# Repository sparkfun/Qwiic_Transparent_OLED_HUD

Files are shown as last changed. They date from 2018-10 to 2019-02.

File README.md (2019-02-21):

SparkFun Qwiic Transparent OLED HUD
========================================

Qwiic WiseChip Transparent OLED HUD (https://www.sparkfun.com/products/14691)

[*SparkFun Qwiic Transparent OLED HUD Hookup Guide (LCD-15079)*](https://www.sparkfun.com/products/14691)

Qwiic Breakout for the WiseChip US-0011GMIAG01 OLED HUD. Clear screens are no longer a thing of the Sci-Fi world! The Qwiic Transparent OLED HUD is SparkFun's answer to all of your futuristic transparent HUD needs. Designed for use in vehicle heads-up displays, this OLED panel is brilliant in the dark but easily visible in daylight. The display is "area colored" meaning that while no one segment can change colors, there are different colored segments on the display.

Repository Contents
-------------------

* **/Hardware** - Eagle design files (.brd, .sch)
* **/Production** - Production panel files (.brd)

Documentation
--------------
* **[Library](https://github.com/sparkfun/SparkFun_WiseChip_HUD_Library)** - Arduino library
* **[Hookup Guide](https://learn.sparkfun.com/tutorials/qwiic-transparent-oled-hud-hookup-guide)** - Basic hookup guide

Product Versions
----------------

* **[LCD-15079](https://www.sparkfun.com/products/15079)** - SparkFun Red Version
* **[SPX-14691](https://www.sparkfun.com/products/14691)** - SparkX Version

License Information
-------------------

This product is _**open source**_! 

Please review the LICENSE.md file for license information. 

If you have any questions or concerns on licensing, please contact techsupport@sparkfun.com.

Distributed as-is; no warranty is given.

- Your friends at SparkFun.

_<COLLABORATION CREDIT>_

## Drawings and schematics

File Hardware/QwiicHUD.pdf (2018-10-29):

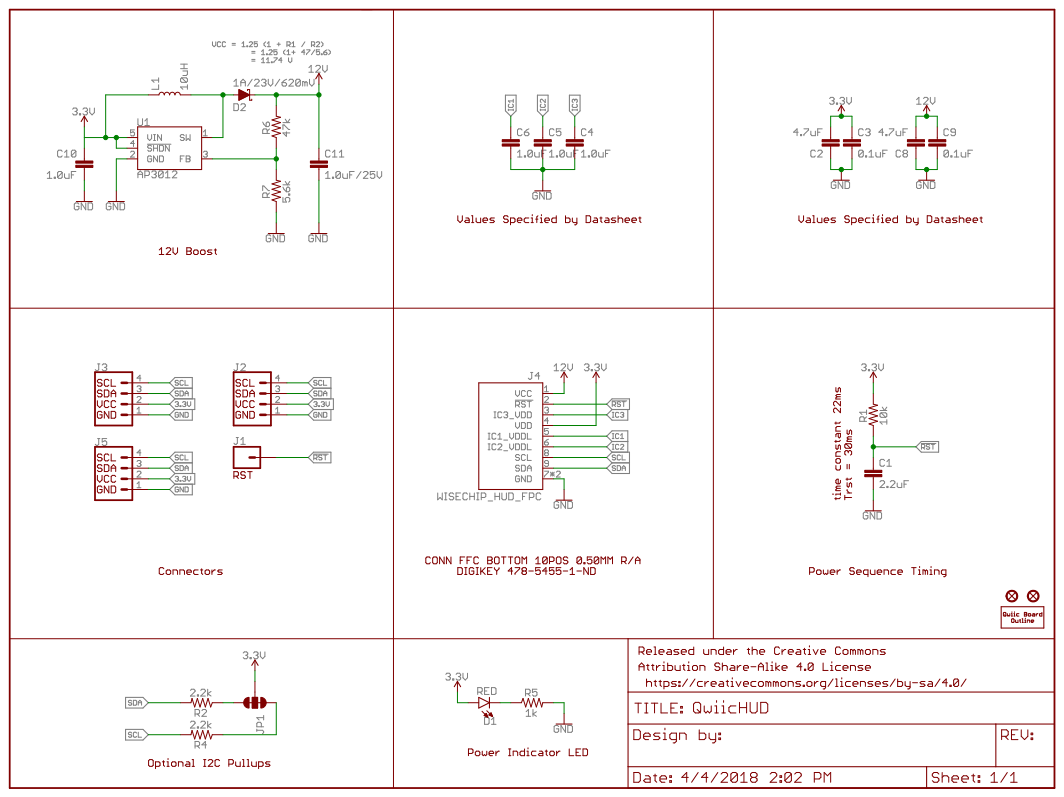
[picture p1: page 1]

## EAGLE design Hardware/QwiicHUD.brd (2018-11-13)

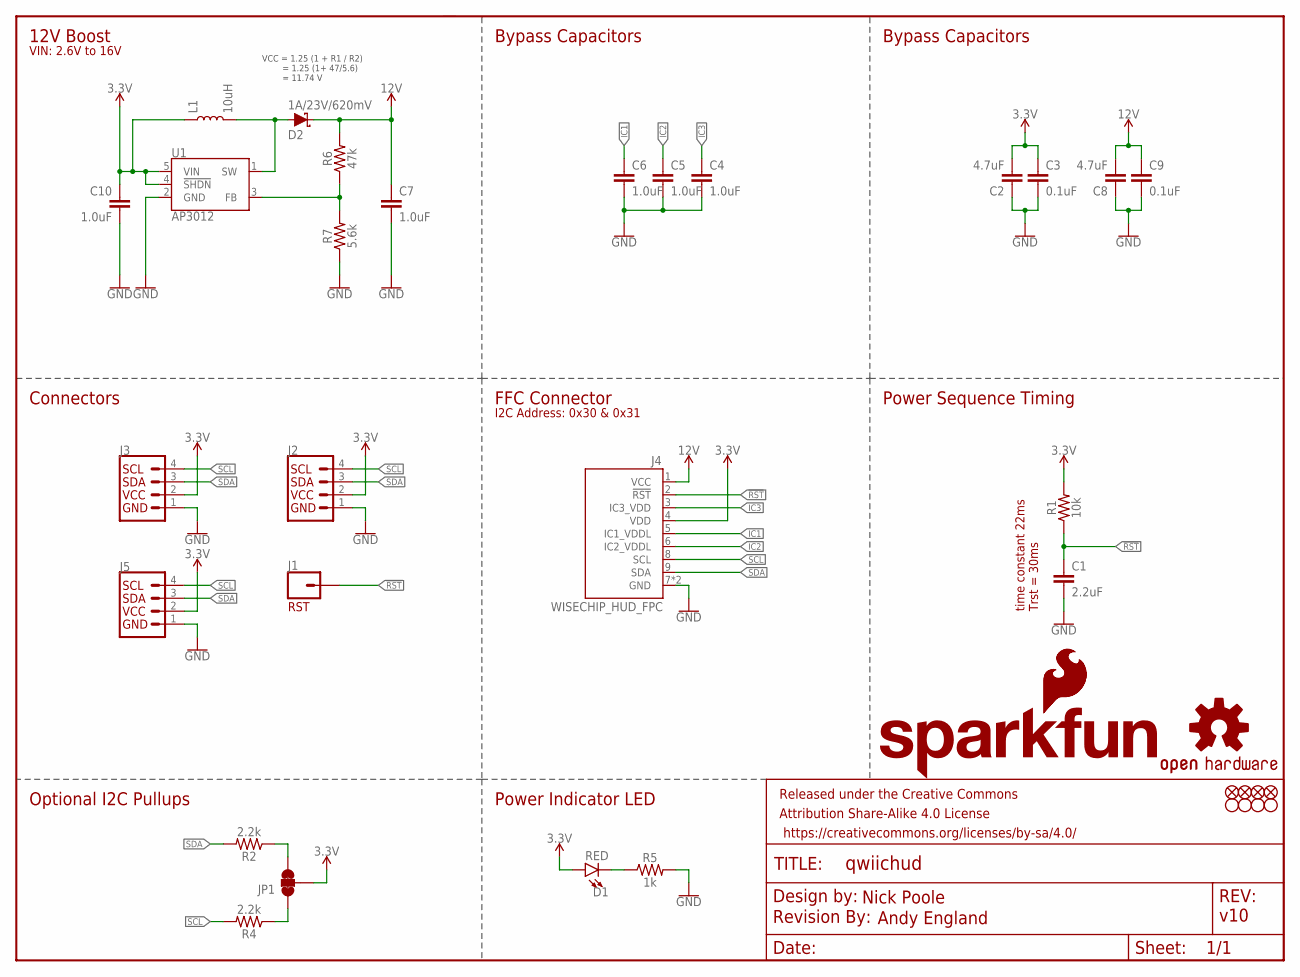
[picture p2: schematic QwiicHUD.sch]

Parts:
C1: 2.2uF; 0603
C2, C8: 4.7uF; 0603
C3, C9: 0.1uF; 0603
C4, C5, C6, C10: 1.0uF; 0603
C7: 1.0uF; 0805
D1: RED; LED-0603
D2: 1A/23V/620mV; SOD-323
FD1, FD2, FD3, FD4: FIDUCIALUFIDUCIAL; FIDUCIAL-MICRO
FRAME1: FRAME-LETTER; CREATIVE_COMMONS
H1, H2, H3, H4: STAND-OFF
J1: CONN_01PTH_NO_SILK_YES_STOP; 1X01_NO_SILK
J2: I2C_STANDARD_NO_SILK; 1X04_NO_SILK
J3, J5: QWIIC_CONNECTORJS-1MM; 1X04_1MM_RA
J4: WISECHIP_HUD_FPC; SERIES6288
JP1: JUMPER-SMT_3_2-NC_TRACE_SILK; SMT-JUMPER_3_2-NC_TRACE_SILK
L1: 10uH; INDUCTOR_4.7UH
LOGO1: OSHW-LOGOS; OSHW-LOGO-S
LOGO2: SFE_LOGO_NAME_FLAME.1_INCH; SFE_LOGO_NAME_FLAME_.1
LOGO3: SFE_LOGO_FLAME.1_INCH; SFE_LOGO_FLAME_.1
LOGO4: REVISION
R1: 10k; 0603
R2, R4: 2.2k; 0603
R5: 1k; 0603
R6: 47k; 0603
R7: 5.6k; 0603
U1: AP3012; SOT23-5

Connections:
3.3V: C2.2, C3.1, C10.1, D1.A, J2.2 (VCC), J3.2, J4.4 (VDD), J5.2, JP1.2, L1.P$1 (1), R1.2, U1.4 (!SHDN!), U1.5 (VIN)
12V: C7.1, C8.2, C9.1, D2.C, J4.1 (VCC), R6.2
!RST: C1.1, J1.1, J4.2 (!RST), R1.1
GND: C1.2, C2.1, C3.2, C4.2, C5.2, C6.2, C7.2, C8.1, C9.2, C10.2, J2.1 (GND), J3.1, J4.7 (GND), J4.10 (GND), J5.1, R5.2, R7.1, U1.2 (GND)
IC1: C6.1, J4.5 (IC1_VDDL)
IC2: C5.1, J4.6 (IC2_VDDL)
IC3: C4.1, J4.3 (IC3_VDD)
unnamed: JP1.3, R2.1
unnamed: JP1.1, R4.1
unnamed: D1.C, R5.1
unnamed: D2.A, L1.P$2 (2), U1.1 (SW)
unnamed: R6.1, R7.2, U1.3 (FB)
SCL: J2.4 (SCL), J3.4, J4.8 (SCL), J5.4, R4.2
SDA: J2.3 (SDA), J3.3, J4.9 (SDA), J5.3, R2.2

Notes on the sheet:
time constant 22ms Trst = 30ms
FFC Connector
Connectors
Power Sequence Timing
Optional I2C Pullups
RST
Power Indicator LED
VCC = 1.25 (1 + R1 / R2) = 1.25 (1+ 47/5.6) = 11.74 V
12V Boost
Nick Poole
Andy England
v10
VIN: 2.6V to 16V
I2C Address: 0x30 & 0x31
Bypass Capacitors

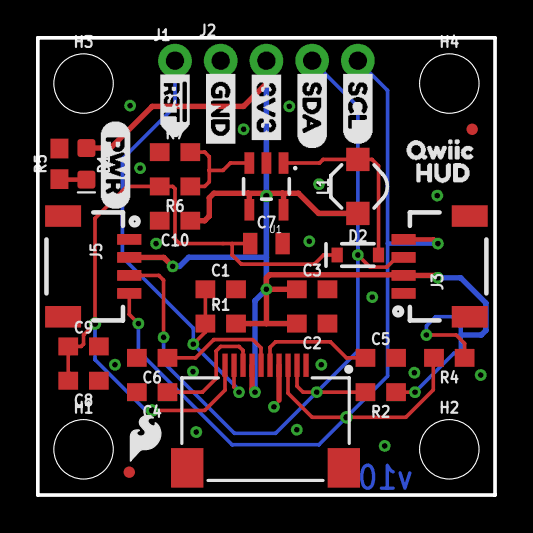
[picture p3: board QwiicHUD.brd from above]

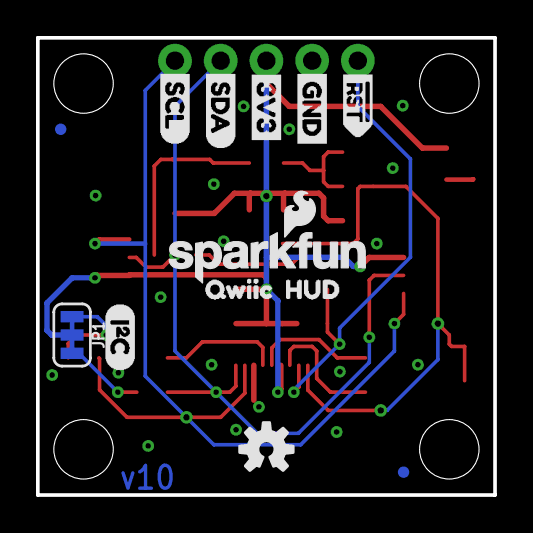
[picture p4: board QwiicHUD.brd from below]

Board: 2 copper layers, 25.4 x 25.4 mm, 55 parts (13 on the bottom side), 14 nets.

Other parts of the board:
U$1, U$14: #RST>
U$2, U$18: QWIIC0
U$3, U$19: HUD1
U$5, U$13: GND
U$6, U$12: 3V3
U$7, U$10: SDA
U$8, U$11: SCL
U$9: (PWR)
U$20: (I_SUPER2_C)

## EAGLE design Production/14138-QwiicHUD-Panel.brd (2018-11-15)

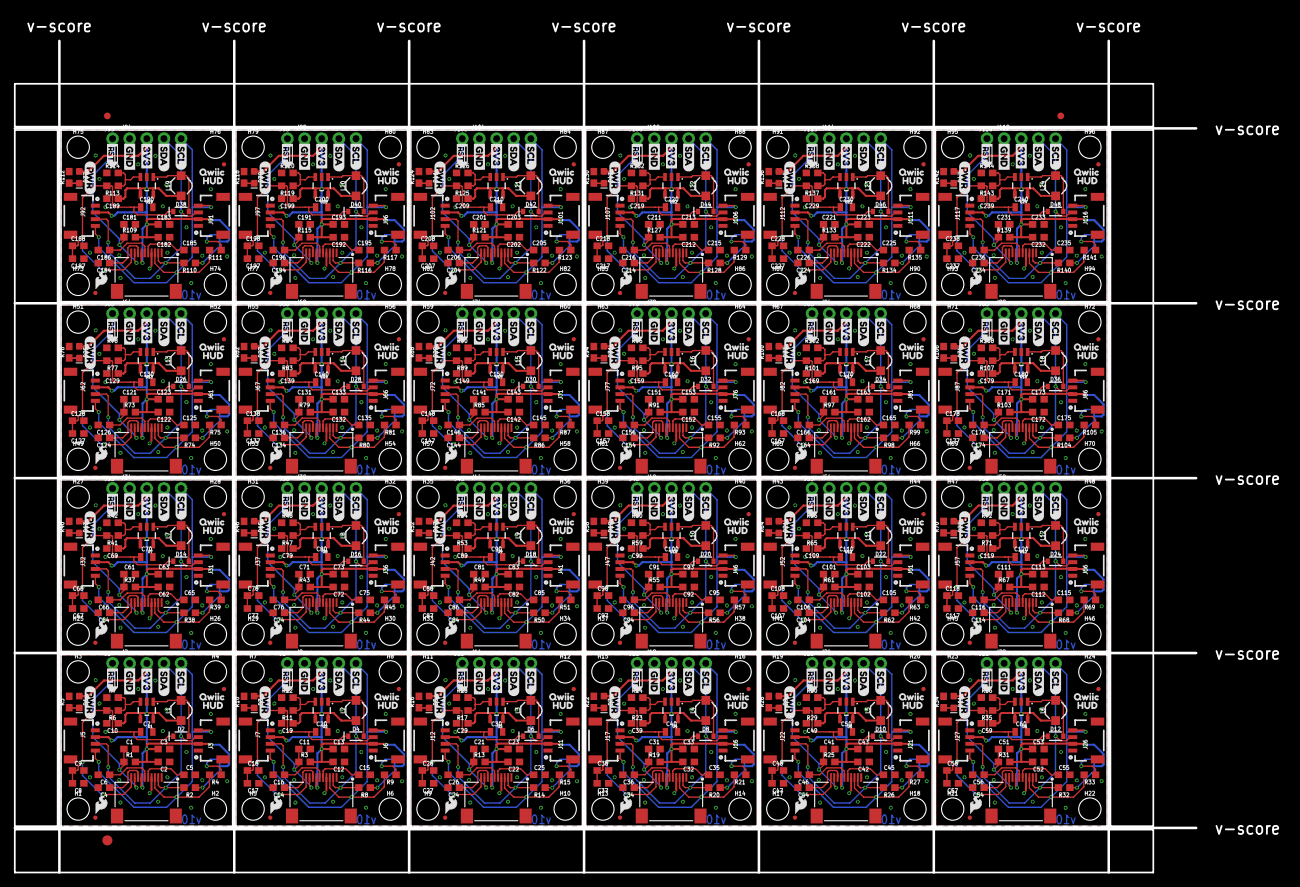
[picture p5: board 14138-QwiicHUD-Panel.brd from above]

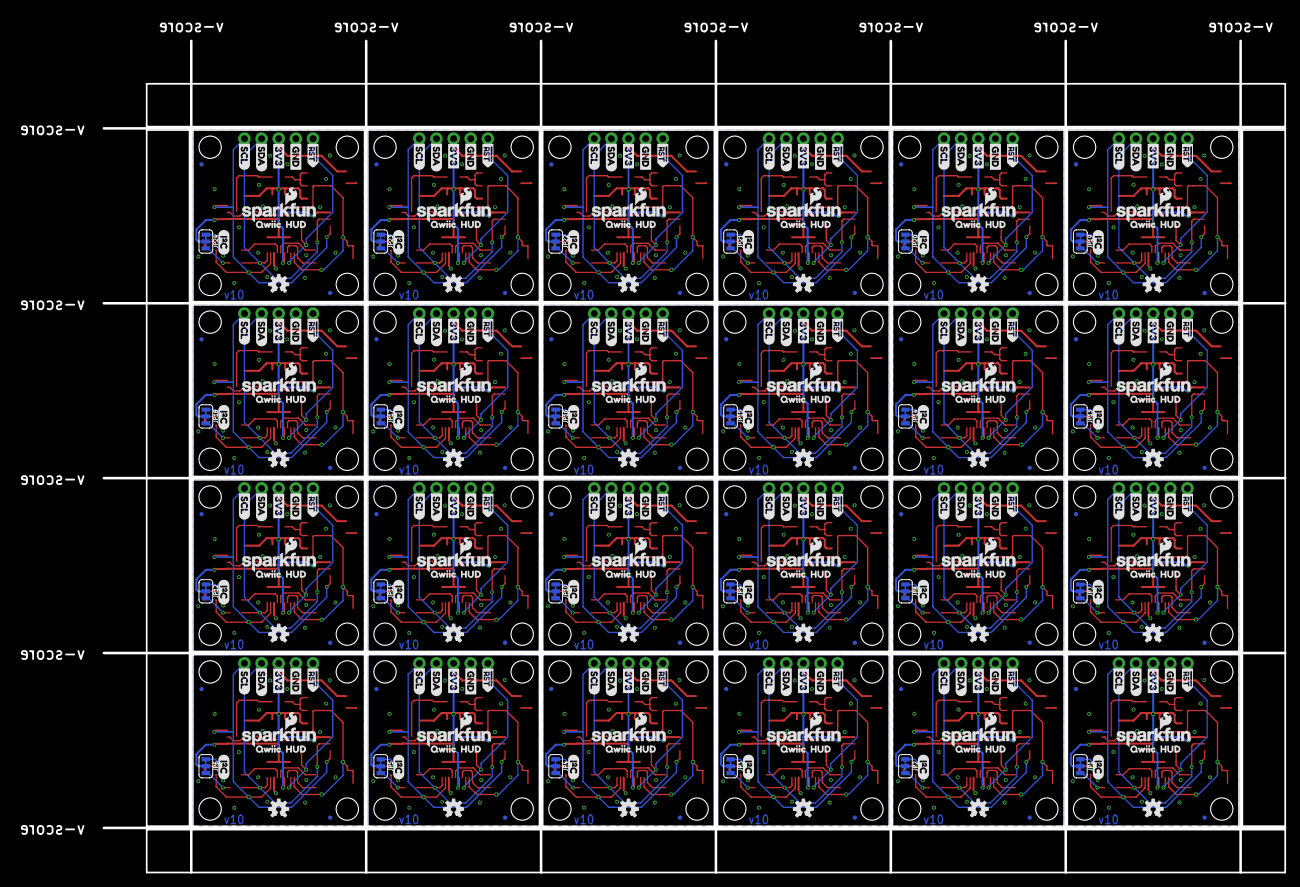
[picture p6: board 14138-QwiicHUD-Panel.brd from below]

Board: 2 copper layers, 175.0 x 123.2 mm, 1275 parts (312 on the bottom side), 336 nets.

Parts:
C1, C11, C21, C31, C41, C51, C61, C71, C81, C91, C101, C111, C121, C131, C141, C151, C161, C171, C181, C191, C201, C211, C221, C231: 2.2uF; 0603
C2, C8, C12, C17, C22, C27, C32, C37, C42, C47, C52, C57, C62, C67, C72, C77, C82, C87, C92, C97, C102, C107, C112, C117, C122, C127, C132, C137, C142, C147, C152, C157, C162, C167, C172, C177, C182, C187, C192, C197, C202, C207, C212, C217, C222, C227, C232, C237: 4.7uF; 0603
C3, C9, C13, C18, C23, C28, C33, C38, C43, C48, C53, C58, C63, C68, C73, C78, C83, C88, C93, C98, C103, C108, C113, C118, C123, C128, C133, C138, C143, C148, C153, C158, C163, C168, C173, C178, C183, C188, C193, C198, C203, C208, C213, C218, C223, C228, C233, C238: 0.1uF; 0603
C4, C5, C6, C10, C14, C15, C16, C19, C24, C25, C26, C29, C34, C35, C36, C39, C44, C45, C46, C49, C54, C55, C56, C59, C64, C65, C66, C69, C74, C75, C76, C79, C84, C85, C86, C89, C94, C95, C96, C99, C104, C105, C106, C109, C114, C115, C116, C119, C124, C125, C126, C129, C134, C135, C136, C139, C144, C145, C146, C149, C154, C155, C156, C159, C164, C165, C166, C169, C174, C175, C176, C179, C184, C185, C186, C189, C194, C195, C196, C199, C204, C205, C206, C209, C214, C215, C216, C219, C224, C225, C226, C229, C234, C235, C236, C239: 1.0uF; 0603
C7, C20, C30, C40, C50, C60, C70, C80, C90, C100, C110, C120, C130, C140, C150, C160, C170, C180, C190, C200, C210, C220, C230, C240: 1.0uF; 0805
D1, D3, D5, D7, D9, D11, D13, D15, D17, D19, D21, D23, D25, D27, D29, D31, D33, D35, D37, D39, D41, D43, D45, D47: RED; LED-0603
D2, D4, D6, D8, D10, D12, D14, D16, D18, D20, D22, D24, D26, D28, D30, D32, D34, D36, D38, D40, D42, D44, D46, D48: 1A/23V/620mV; SOD-323
E$1, E$2: FIDUCIAL-1X2
E$3: FIDUCIAL-1.5X3
FD1, FD2, FD3, FD4, FD5, FD6, FD7, FD8, FD9, FD10, FD11, FD12, FD13, FD14, FD15, FD16, FD17, FD18, FD19, FD20, FD21, FD22, FD23, FD24, FD25, FD26, FD27, FD28, FD29, FD30, FD31, FD32, FD33, FD34, FD35, FD36, FD37, FD38, FD39, FD40, FD41, FD42, FD43, FD44, FD45, FD46, FD47, FD48, FD49, FD50, FD51, FD52, FD53, FD54, FD55, FD56, FD57, FD58, FD59, FD60, FD61, FD62, FD63, FD64, FD65, FD66, FD67, FD68, FD69, FD70, FD71, FD72, FD73, FD74, FD75, FD76, FD77, FD78, FD79, FD80, FD81, FD82, FD83, FD84, FD85, FD86, FD87, FD88, FD89, FD90, FD91, FD92, FD93, FD94, FD95, FD96: FIDUCIALUFIDUCIAL; FIDUCIAL-MICRO
H1, H2, H3, H4, H5, H6, H7, H8, H9, H10, H11, H12, H13, H14, H15, H16, H17, H18, H19, H20, H21, H22, H23, H24, H25, H26, H27, H28, H29, H30, H31, H32, H33, H34, H35, H36, H37, H38, H39, H40, H41, H42, H43, H44, H45, H46, H47, H48, H49, H50, H51, H52, H53, H54, H55, H56, H57, H58, H59, H60, H61, H62, H63, H64, H65, H66, H67, H68, H69, H70, H71, H72, H73, H74, H75, H76, H77, H78, H79, H80, H81, H82, H83, H84, H85, H86, H87, H88, H89, H90, H91, H92, H93, H94, H95, H96: STAND-OFF
J1, J8, J13, J18, J23, J28, J33, J38, J43, J48, J53, J58, J63, J68, J73, J78, J83, J88, J93, J98, J103, J108, J113, J118: 1X01_NO_SILK
J2, J9, J14, J19, J24, J29, J34, J39, J44, J49, J54, J59, J64, J69, J74, J79, J84, J89, J94, J99, J104, J109, J114, J119: 1X04_NO_SILK
J3, J5, J6, J7, J11, J12, J16, J17, J21, J22, J26, J27, J31, J32, J36, J37, J41, J42, J46, J47, J51, J52, J56, J57, J61, J62, J66, J67, J71, J72, J76, J77, J81, J82, J86, J87, J91, J92, J96, J97, J101, J102, J106, J107, J111, J112, J116, J117: 1X04_1MM_RA
J4, J10, J15, J20, J25, J30, J35, J40, J45, J50, J55, J60, J65, J70, J75, J80, J85, J90, J95, J100, J105, J110, J115, J120: WISECHIP_HUD_FPC; SERIES6288
JP1, JP2, JP3, JP4, JP5, JP6, JP7, JP8, JP9, JP10, JP11, JP12, JP13, JP14, JP15, JP16, JP17, JP18, JP19, JP20, JP21, JP22, JP23, JP24: SMT-JUMPER_3_2-NC_TRACE_SILK
L1, L2, L3, L4, L5, L6, L7, L8, L9, L10, L11, L12, L13, L14, L15, L16, L17, L18, L19, L20, L21, L22, L23, L24: 10uH; INDUCTOR_4.7UH
LOGO1, LOGO6, LOGO9, LOGO12, LOGO15, LOGO18, LOGO21, LOGO24, LOGO27, LOGO30, LOGO33, LOGO36, LOGO39, LOGO42, LOGO45, LOGO48, LOGO51, LOGO54, LOGO57, LOGO60, LOGO63, LOGO66, LOGO69, LOGO72: OSHW-LOGOS; OSHW-LOGO-S
LOGO2, LOGO4, LOGO7, LOGO10, LOGO13, LOGO16, LOGO19, LOGO22, LOGO25, LOGO28, LOGO31, LOGO34, LOGO37, LOGO40, LOGO43, LOGO46, LOGO49, LOGO52, LOGO55, LOGO58, LOGO61, LOGO64, LOGO67, LOGO70: SFE_LOGO_NAME_FLAME.1_INCH; SFE_LOGO_NAME_FLAME_.1
LOGO3, LOGO5, LOGO8, LOGO11, LOGO14, LOGO17, LOGO20, LOGO23, LOGO26, LOGO29, LOGO32, LOGO35, LOGO38, LOGO41, LOGO44, LOGO47, LOGO50, LOGO53, LOGO56, LOGO59, LOGO62, LOGO65, LOGO68, LOGO71: SFE_LOGO_FLAME.1_INCH; SFE_LOGO_FLAME_.1
R1, R3, R13, R19, R25, R31, R37, R43, R49, R55, R61, R67, R73, R79, R85, R91, R97, R103, R109, R115, R121, R127, R133, R139: 10k; 0603
R2, R4, R8, R9, R14, R15, R20, R21, R26, R27, R32, R33, R38, R39, R44, R45, R50, R51, R56, R57, R62, R63, R68, R69, R74, R75, R80, R81, R86, R87, R92, R93, R98, R99, R104, R105, R110, R111, R116, R117, R122, R123, R128, R129, R134, R135, R140, R141: 2.2k; 0603
R5, R10, R16, R22, R28, R34, R40, R46, R52, R58, R64, R70, R76, R82, R88, R94, R100, R106, R112, R118, R124, R130, R136, R142: 1k; 0603
R6, R11, R17, R23, R29, R35, R41, R47, R53, R59, R65, R71, R77, R83, R89, R95, R101, R107, R113, R119, R125, R131, R137, R143: 47k; 0603
R7, R12, R18, R24, R30, R36, R42, R48, R54, R60, R66, R72, R78, R84, R90, R96, R102, R108, R114, R120, R126, R132, R138, R144: 5.6k; 0603
U1, U2, U3, U4, U5, U6, U7, U8, U9, U10, U11, U12, U13, U14, U15, U16, U17, U18, U19, U20, U21, U22, U23, U24: AP3012; SOT23-5
U$1, U$4, U$14, U$27, U$33, U$43, U$49, U$59, U$65, U$75, U$81, U$91, U$97, U$107, U$113, U$123, U$129, U$139, U$145, U$155, U$161, U$171, U$177, U$187, U$193, U$203, U$209, U$219, U$225, U$235, U$241, U$251, U$257, U$267, U$273, U$283, U$289, U$299, U$305, U$315, U$321, U$331, U$337, U$347, U$353, U$363, U$369, U$379: #RST>
U$2, U$18, U$28, U$31, U$44, U$47, U$60, U$63, U$76, U$79, U$92, U$95, U$108, U$111, U$124, U$127, U$140, U$143, U$156, U$159, U$172, U$175, U$188, U$191, U$204, U$207, U$220, U$223, U$236, U$239, U$252, U$255, U$268, U$271, U$284, U$287, U$300, U$303, U$316, U$319, U$332, U$335, U$348, U$351, U$364, U$367, U$380, U$383: QWIIC0
U$3, U$19, U$29, U$32, U$45, U$48, U$61, U$64, U$77, U$80, U$93, U$96, U$109, U$112, U$125, U$128, U$141, U$144, U$157, U$160, U$173, U$176, U$189, U$192, U$205, U$208, U$221, U$224, U$237, U$240, U$253, U$256, U$269, U$272, U$285, U$288, U$301, U$304, U$317, U$320, U$333, U$336, U$349, U$352, U$365, U$368, U$381, U$384: HUD1
U$5, U$13, U$15, U$26, U$34, U$42, U$50, U$58, U$66, U$74, U$82, U$90, U$98, U$106, U$114, U$122, U$130, U$138, U$146, U$154, U$162, U$170, U$178, U$186, U$194, U$202, U$210, U$218, U$226, U$234, U$242, U$250, U$258, U$266, U$274, U$282, U$290, U$298, U$306, U$314, U$322, U$330, U$338, U$346, U$354, U$362, U$370, U$378: GND
U$6, U$12, U$16, U$25, U$35, U$41, U$51, U$57, U$67, U$73, U$83, U$89, U$99, U$105, U$115, U$121, U$131, U$137, U$147, U$153, U$163, U$169, U$179, U$185, U$195, U$201, U$211, U$217, U$227, U$233, U$243, U$249, U$259, U$265, U$275, U$281, U$291, U$297, U$307, U$313, U$323, U$329, U$339, U$345, U$355, U$361, U$371, U$377: 3V3
U$7, U$10, U$17, U$23, U$36, U$39, U$52, U$55, U$68, U$71, U$84, U$87, U$100, U$103, U$116, U$119, U$132, U$135, U$148, U$151, U$164, U$167, U$180, U$183, U$196, U$199, U$212, U$215, U$228, U$231, U$244, U$247, U$260, U$263, U$276, U$279, U$292, U$295, U$308, U$311, U$324, U$327, U$340, U$343, U$356, U$359, U$372, U$375: SDA
U$8, U$11, U$21, U$24, U$37, U$40, U$53, U$56, U$69, U$72, U$85, U$88, U$101, U$104, U$117, U$120, U$133, U$136, U$149, U$152, U$165, U$168, U$181, U$184, U$197, U$200, U$213, U$216, U$229, U$232, U$245, U$248, U$261, U$264, U$277, U$280, U$293, U$296, U$309, U$312, U$325, U$328, U$341, U$344, U$357, U$360, U$373, U$376: SCL
U$9, U$22, U$38, U$54, U$70, U$86, U$102, U$118, U$134, U$150, U$166, U$182, U$198, U$214, U$230, U$246, U$262, U$278, U$294, U$310, U$326, U$342, U$358, U$374: (PWR)
U$20, U$30, U$46, U$62, U$78, U$94, U$110, U$126, U$142, U$158, U$174, U$190, U$206, U$222, U$238, U$254, U$270, U$286, U$302, U$318, U$334, U$350, U$366, U$382: (I_SUPER2_C)

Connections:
3.3V: C2.2, C3.1, C10.1, D1.A, J2.2, J3.2, J4.4, J5.2, JP1.2, L1.P$1, R1.2, U1.4, U1.5
3.3V1: C12.2, C13.1, C19.1, D3.A, J6.2, J7.2, J9.2, J10.4, JP2.2, L2.P$1, R3.2, U2.4, U2.5
3.3V2: C22.2, C23.1, C29.1, D5.A, J11.2, J12.2, J14.2, J15.4, JP3.2, L3.P$1, R13.2, U3.4, U3.5
3.3V3: C32.2, C33.1, C39.1, D7.A, J16.2, J17.2, J19.2, J20.4, JP4.2, L4.P$1, R19.2, U4.4, U4.5
3.3V4: C42.2, C43.1, C49.1, D9.A, J21.2, J22.2, J24.2, J25.4, JP5.2, L5.P$1, R25.2, U5.4, U5.5
3.3V5: C52.2, C53.1, C59.1, D11.A, J26.2, J27.2, J29.2, J30.4, JP6.2, L6.P$1, R31.2, U6.4, U6.5
3.3V6: C62.2, C63.1, C69.1, D13.A, J31.2, J32.2, J34.2, J35.4, JP7.2, L7.P$1, R37.2, U7.4, U7.5
3.3V7: C72.2, C73.1, C79.1, D15.A, J36.2, J37.2, J39.2, J40.4, JP8.2, L8.P$1, R43.2, U8.4, U8.5
3.3V8: C82.2, C83.1, C89.1, D17.A, J41.2, J42.2, J44.2, J45.4, JP9.2, L9.P$1, R49.2, U9.4, U9.5
3.3V9: C92.2, C93.1, C99.1, D19.A, J46.2, J47.2, J49.2, J50.4, JP10.2, L10.P$1, R55.2, U10.4, U10.5
3.3V10: C102.2, C103.1, C109.1, D21.A, J51.2, J52.2, J54.2, J55.4, JP11.2, L11.P$1, R61.2, U11.4, U11.5
3.3V11: C112.2, C113.1, C119.1, D23.A, J56.2, J57.2, J59.2, J60.4, JP12.2, L12.P$1, R67.2, U12.4, U12.5
3.3V12: C122.2, C123.1, C129.1, D25.A, J61.2, J62.2, J64.2, J65.4, JP13.2, L13.P$1, R73.2, U13.4, U13.5
3.3V13: C132.2, C133.1, C139.1, D27.A, J66.2, J67.2, J69.2, J70.4, JP14.2, L14.P$1, R79.2, U14.4, U14.5
3.3V14: C142.2, C143.1, C149.1, D29.A, J71.2, J72.2, J74.2, J75.4, JP15.2, L15.P$1, R85.2, U15.4, U15.5
3.3V15: C152.2, C153.1, C159.1, D31.A, J76.2, J77.2, J79.2, J80.4, JP16.2, L16.P$1, R91.2, U16.4, U16.5
3.3V16: C162.2, C163.1, C169.1, D33.A, J81.2, J82.2, J84.2, J85.4, JP17.2, L17.P$1, R97.2, U17.4, U17.5
3.3V17: C172.2, C173.1, C179.1, D35.A, J86.2, J87.2, J89.2, J90.4, JP18.2, L18.P$1, R103.2, U18.4, U18.5
3.3V18: C182.2, C183.1, C189.1, D37.A, J91.2, J92.2, J94.2, J95.4, JP19.2, L19.P$1, R109.2, U19.4, U19.5
3.3V19: C192.2, C193.1, C199.1, D39.A, J96.2, J97.2, J99.2, J100.4, JP20.2, L20.P$1, R115.2, U20.4, U20.5
3.3V20: C202.2, C203.1, C209.1, D41.A, J101.2, J102.2, J104.2, J105.4, JP21.2, L21.P$1, R121.2, U21.4, U21.5
3.3V21: C212.2, C213.1, C219.1, D43.A, J106.2, J107.2, J109.2, J110.4, JP22.2, L22.P$1, R127.2, U22.4, U22.5
3.3V22: C222.2, C223.1, C229.1, D45.A, J111.2, J112.2, J114.2, J115.4, JP23.2, L23.P$1, R133.2, U23.4, U23.5
3.3V23: C232.2, C233.1, C239.1, D47.A, J116.2, J117.2, J119.2, J120.4, JP24.2, L24.P$1, R139.2, U24.4, U24.5
12V: C7.1, C8.2, C9.1, D2.C, J4.1, R6.2
12V1: C17.2, C18.1, C20.1, D4.C, J10.1, R11.2
12V2: C27.2, C28.1, C30.1, D6.C, J15.1, R17.2
12V3: C37.2, C38.1, C40.1, D8.C, J20.1, R23.2
12V4: C47.2, C48.1, C50.1, D10.C, J25.1, R29.2
12V5: C57.2, C58.1, C60.1, D12.C, J30.1, R35.2
12V6: C67.2, C68.1, C70.1, D14.C, J35.1, R41.2
12V7: C77.2, C78.1, C80.1, D16.C, J40.1, R47.2
12V8: C87.2, C88.1, C90.1, D18.C, J45.1, R53.2
12V9: C97.2, C98.1, C100.1, D20.C, J50.1, R59.2
12V10: C107.2, C108.1, C110.1, D22.C, J55.1, R65.2
12V11: C117.2, C118.1, C120.1, D24.C, J60.1, R71.2
12V12: C127.2, C128.1, C130.1, D26.C, J65.1, R77.2
12V13: C137.2, C138.1, C140.1, D28.C, J70.1, R83.2
12V14: C147.2, C148.1, C150.1, D30.C, J75.1, R89.2
12V15: C157.2, C158.1, C160.1, D32.C, J80.1, R95.2
12V16: C167.2, C168.1, C170.1, D34.C, J85.1, R101.2
12V17: C177.2, C178.1, C180.1, D36.C, J90.1, R107.2
12V18: C187.2, C188.1, C190.1, D38.C, J95.1, R113.2
12V19: C197.2, C198.1, C200.1, D40.C, J100.1, R119.2
12V20: C207.2, C208.1, C210.1, D42.C, J105.1, R125.2
12V21: C217.2, C218.1, C220.1, D44.C, J110.1, R131.2
12V22: C227.2, C228.1, C230.1, D46.C, J115.1, R137.2
12V23: C237.2, C238.1, C240.1, D48.C, J120.1, R143.2
!RST: C1.1, J1.1, J4.2, R1.1
!RST1: C11.1, J8.1, J10.2, R3.1
!RST2: C21.1, J13.1, J15.2, R13.1
!RST3: C31.1, J18.1, J20.2, R19.1
!RST4: C41.1, J23.1, J25.2, R25.1
!RST5: C51.1, J28.1, J30.2, R31.1
!RST6: C61.1, J33.1, J35.2, R37.1
!RST7: C71.1, J38.1, J40.2, R43.1
!RST8: C81.1, J43.1, J45.2, R49.1
!RST9: C91.1, J48.1, J50.2, R55.1
!RST10: C101.1, J53.1, J55.2, R61.1
!RST11: C111.1, J58.1, J60.2, R67.1
!RST12: C121.1, J63.1, J65.2, R73.1
!RST13: C131.1, J68.1, J70.2, R79.1
!RST14: C141.1, J73.1, J75.2, R85.1
!RST15: C151.1, J78.1, J80.2, R91.1
!RST16: C161.1, J83.1, J85.2, R97.1
!RST17: C171.1, J88.1, J90.2, R103.1
!RST18: C181.1, J93.1, J95.2, R109.1
!RST19: C191.1, J98.1, J100.2, R115.1
!RST20: C201.1, J103.1, J105.2, R121.1
!RST21: C211.1, J108.1, J110.2, R127.1
!RST22: C221.1, J113.1, J115.2, R133.1
!RST23: C231.1, J118.1, J120.2, R139.1
GND: C1.2, C2.1, C3.2, C4.2, C5.2, C6.2, C7.2, C8.1, C9.2, C10.2, J2.1, J3.1, J4.7, J4.10, J5.1, R5.2, R7.1, U1.2
GND1: C11.2, C12.1, C13.2, C14.2, C15.2, C16.2, C17.1, C18.2, C19.2, C20.2, J6.1, J7.1, J9.1, J10.7, J10.10, R10.2, R12.1, U2.2
GND2: C21.2, C22.1, C23.2, C24.2, C25.2, C26.2, C27.1, C28.2, C29.2, C30.2, J11.1, J12.1, J14.1, J15.7, J15.10, R16.2, R18.1, U3.2
GND3: C31.2, C32.1, C33.2, C34.2, C35.2, C36.2, C37.1, C38.2, C39.2, C40.2, J16.1, J17.1, J19.1, J20.7, J20.10, R22.2, R24.1, U4.2
GND4: C41.2, C42.1, C43.2, C44.2, C45.2, C46.2, C47.1, C48.2, C49.2, C50.2, J21.1, J22.1, J24.1, J25.7, J25.10, R28.2, R30.1, U5.2
GND5: C51.2, C52.1, C53.2, C54.2, C55.2, C56.2, C57.1, C58.2, C59.2, C60.2, J26.1, J27.1, J29.1, J30.7, J30.10, R34.2, R36.1, U6.2
GND6: C61.2, C62.1, C63.2, C64.2, C65.2, C66.2, C67.1, C68.2, C69.2, C70.2, J31.1, J32.1, J34.1, J35.7, J35.10, R40.2, R42.1, U7.2
GND7: C71.2, C72.1, C73.2, C74.2, C75.2, C76.2, C77.1, C78.2, C79.2, C80.2, J36.1, J37.1, J39.1, J40.7, J40.10, R46.2, R48.1, U8.2
GND8: C81.2, C82.1, C83.2, C84.2, C85.2, C86.2, C87.1, C88.2, C89.2, C90.2, J41.1, J42.1, J44.1, J45.7, J45.10, R52.2, R54.1, U9.2
GND9: C91.2, C92.1, C93.2, C94.2, C95.2, C96.2, C97.1, C98.2, C99.2, C100.2, J46.1, J47.1, J49.1, J50.7, J50.10, R58.2, R60.1, U10.2
GND10: C101.2, C102.1, C103.2, C104.2, C105.2, C106.2, C107.1, C108.2, C109.2, C110.2, J51.1, J52.1, J54.1, J55.7, J55.10, R64.2, R66.1, U11.2
GND11: C111.2, C112.1, C113.2, C114.2, C115.2, C116.2, C117.1, C118.2, C119.2, C120.2, J56.1, J57.1, J59.1, J60.7, J60.10, R70.2, R72.1, U12.2
GND12: C121.2, C122.1, C123.2, C124.2, C125.2, C126.2, C127.1, C128.2, C129.2, C130.2, J61.1, J62.1, J64.1, J65.7, J65.10, R76.2, R78.1, U13.2
GND13: C131.2, C132.1, C133.2, C134.2, C135.2, C136.2, C137.1, C138.2, C139.2, C140.2, J66.1, J67.1, J69.1, J70.7, J70.10, R82.2, R84.1, U14.2
GND14: C141.2, C142.1, C143.2, C144.2, C145.2, C146.2, C147.1, C148.2, C149.2, C150.2, J71.1, J72.1, J74.1, J75.7, J75.10, R88.2, R90.1, U15.2
GND15: C151.2, C152.1, C153.2, C154.2, C155.2, C156.2, C157.1, C158.2, C159.2, C160.2, J76.1, J77.1, J79.1, J80.7, J80.10, R94.2, R96.1, U16.2
GND16: C161.2, C162.1, C163.2, C164.2, C165.2, C166.2, C167.1, C168.2, C169.2, C170.2, J81.1, J82.1, J84.1, J85.7, J85.10, R100.2, R102.1, U17.2
GND17: C171.2, C172.1, C173.2, C174.2, C175.2, C176.2, C177.1, C178.2, C179.2, C180.2, J86.1, J87.1, J89.1, J90.7, J90.10, R106.2, R108.1, U18.2
GND18: C181.2, C182.1, C183.2, C184.2, C185.2, C186.2, C187.1, C188.2, C189.2, C190.2, J91.1, J92.1, J94.1, J95.7, J95.10, R112.2, R114.1, U19.2
GND19: C191.2, C192.1, C193.2, C194.2, C195.2, C196.2, C197.1, C198.2, C199.2, C200.2, J96.1, J97.1, J99.1, J100.7, J100.10, R118.2, R120.1, U20.2
GND20: C201.2, C202.1, C203.2, C204.2, C205.2, C206.2, C207.1, C208.2, C209.2, C210.2, J101.1, J102.1, J104.1, J105.7, J105.10, R124.2, R126.1, U21.2
GND21: C211.2, C212.1, C213.2, C214.2, C215.2, C216.2, C217.1, C218.2, C219.2, C220.2, J106.1, J107.1, J109.1, J110.7, J110.10, R130.2, R132.1, U22.2
GND22: C221.2, C222.1, C223.2, C224.2, C225.2, C226.2, C227.1, C228.2, C229.2, C230.2, J111.1, J112.1, J114.1, J115.7, J115.10, R136.2, R138.1, U23.2
GND23: C231.2, C232.1, C233.2, C234.2, C235.2, C236.2, C237.1, C238.2, C239.2, C240.2, J116.1, J117.1, J119.1, J120.7, J120.10, R142.2, R144.1, U24.2
IC1: C6.1, J4.5
IC2: C5.1, J4.6
IC3: C4.1, J4.3
IC4: C14.1, J10.3
IC5: C16.1, J10.5
IC6: C15.1, J10.6
IC7: C24.1, J15.3
IC8: C26.1, J15.5
IC9: C25.1, J15.6
IC10: C34.1, J20.3
IC11: C36.1, J20.5
IC12: C35.1, J20.6
IC13: C44.1, J25.3
IC14: C46.1, J25.5
IC15: C45.1, J25.6
IC16: C54.1, J30.3
IC17: C56.1, J30.5
IC18: C55.1, J30.6
IC19: C64.1, J35.3
IC20: C66.1, J35.5
IC21: C65.1, J35.6
IC22: C74.1, J40.3
IC23: C76.1, J40.5
IC24: C75.1, J40.6
IC25: C84.1, J45.3
IC26: C86.1, J45.5
IC27: C85.1, J45.6
IC28: C94.1, J50.3
IC29: C96.1, J50.5
IC30: C95.1, J50.6
IC31: C104.1, J55.3
IC32: C106.1, J55.5
IC33: C105.1, J55.6
IC34: C114.1, J60.3
IC35: C116.1, J60.5
IC36: C115.1, J60.6
IC37: C124.1, J65.3
IC38: C126.1, J65.5
IC39: C125.1, J65.6
IC40: C134.1, J70.3
IC41: C136.1, J70.5
IC42: C135.1, J70.6
IC43: C144.1, J75.3
IC44: C146.1, J75.5
IC45: C145.1, J75.6
IC46: C154.1, J80.3
IC47: C156.1, J80.5
IC48: C155.1, J80.6
IC49: C164.1, J85.3
IC50: C166.1, J85.5
IC51: C165.1, J85.6
IC52: C174.1, J90.3
IC53: C176.1, J90.5
IC54: C175.1, J90.6
IC55: C184.1, J95.3
IC56: C186.1, J95.5
IC57: C185.1, J95.6
IC58: C194.1, J100.3
IC59: C196.1, J100.5
IC60: C195.1, J100.6
IC61: C204.1, J105.3
IC62: C206.1, J105.5
IC63: C205.1, J105.6
IC64: C214.1, J110.3
IC65: C216.1, J110.5
IC66: C215.1, J110.6
IC67: C224.1, J115.3
IC68: C226.1, J115.5
IC69: C225.1, J115.6
IC70: C234.1, J120.3
IC71: C236.1, J120.5
IC72: C235.1, J120.6
unnamed: JP1.3, R2.1
unnamed: JP1.1, R4.1
unnamed: D1.C, R5.1
unnamed: D2.A, L1.P$2, U1.1
unnamed: R6.1, R7.2, U1.3
unnamed: JP2.3, R8.1
unnamed: JP2.1, R9.1
unnamed: D3.C, R10.1
unnamed: D4.A, L2.P$2, U2.1
unnamed: R11.1, R12.2, U2.3
unnamed: JP3.3, R14.1
unnamed: JP3.1, R15.1
unnamed: D5.C, R16.1
unnamed: D6.A, L3.P$2, U3.1
unnamed: R17.1, R18.2, U3.3
unnamed: JP4.3, R20.1
unnamed: JP4.1, R21.1
unnamed: D7.C, R22.1
unnamed: D8.A, L4.P$2, U4.1
unnamed: R23.1, R24.2, U4.3
unnamed: JP5.3, R26.1
unnamed: JP5.1, R27.1
unnamed: D9.C, R28.1
unnamed: D10.A, L5.P$2, U5.1
unnamed: R29.1, R30.2, U5.3
unnamed: JP6.3, R32.1
unnamed: JP6.1, R33.1
unnamed: D11.C, R34.1
unnamed: D12.A, L6.P$2, U6.1
unnamed: R35.1, R36.2, U6.3
unnamed: JP7.3, R38.1
unnamed: JP7.1, R39.1
unnamed: D13.C, R40.1
unnamed: D14.A, L7.P$2, U7.1
unnamed: R41.1, R42.2, U7.3
unnamed: JP8.3, R44.1
unnamed: JP8.1, R45.1
unnamed: D15.C, R46.1
unnamed: D16.A, L8.P$2, U8.1
unnamed: R47.1, R48.2, U8.3
unnamed: JP9.3, R50.1
unnamed: JP9.1, R51.1
unnamed: D17.C, R52.1
unnamed: D18.A, L9.P$2, U9.1
unnamed: R53.1, R54.2, U9.3
unnamed: JP10.3, R56.1
unnamed: JP10.1, R57.1
unnamed: D19.C, R58.1
unnamed: D20.A, L10.P$2, U10.1
unnamed: R59.1, R60.2, U10.3
unnamed: JP11.3, R62.1
unnamed: JP11.1, R63.1
unnamed: D21.C, R64.1
unnamed: D22.A, L11.P$2, U11.1
unnamed: R65.1, R66.2, U11.3
unnamed: JP12.3, R68.1
unnamed: JP12.1, R69.1
unnamed: D23.C, R70.1
unnamed: D24.A, L12.P$2, U12.1
unnamed: R71.1, R72.2, U12.3
unnamed: JP13.3, R74.1
unnamed: JP13.1, R75.1
unnamed: D25.C, R76.1
unnamed: D26.A, L13.P$2, U13.1
unnamed: R77.1, R78.2, U13.3
unnamed: JP14.3, R80.1
unnamed: JP14.1, R81.1
unnamed: D27.C, R82.1
unnamed: D28.A, L14.P$2, U14.1
unnamed: R83.1, R84.2, U14.3
unnamed: JP15.3, R86.1
unnamed: JP15.1, R87.1
unnamed: D29.C, R88.1
unnamed: D30.A, L15.P$2, U15.1
unnamed: R89.1, R90.2, U15.3
unnamed: JP16.3, R92.1
unnamed: JP16.1, R93.1
unnamed: D31.C, R94.1
unnamed: D32.A, L16.P$2, U16.1
unnamed: R95.1, R96.2, U16.3
unnamed: JP17.3, R98.1
unnamed: JP17.1, R99.1
unnamed: D33.C, R100.1
unnamed: D34.A, L17.P$2, U17.1
unnamed: R101.1, R102.2, U17.3
unnamed: JP18.3, R104.1
unnamed: JP18.1, R105.1
unnamed: D35.C, R106.1
unnamed: D36.A, L18.P$2, U18.1
unnamed: R107.1, R108.2, U18.3
unnamed: JP19.3, R110.1
unnamed: JP19.1, R111.1
unnamed: D37.C, R112.1
unnamed: D38.A, L19.P$2, U19.1
unnamed: R113.1, R114.2, U19.3
unnamed: JP20.3, R116.1
unnamed: JP20.1, R117.1
unnamed: D39.C, R118.1
unnamed: D40.A, L20.P$2, U20.1
unnamed: R119.1, R120.2, U20.3
unnamed: JP21.3, R122.1
unnamed: JP21.1, R123.1
unnamed: D41.C, R124.1
unnamed: D42.A, L21.P$2, U21.1
unnamed: R125.1, R126.2, U21.3
unnamed: JP22.3, R128.1
unnamed: JP22.1, R129.1
unnamed: D43.C, R130.1
unnamed: D44.A, L22.P$2, U22.1
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

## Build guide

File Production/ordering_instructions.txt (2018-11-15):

panel size, 169x117mm
PCB thickness, 1.6mm
number of layers, 2
soldermask color, Red
silkscreen color, White
oz copper, 1oz
finish, HASL lead free
stencils, none
pcs per panel, 24

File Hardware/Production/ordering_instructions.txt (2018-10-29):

panel size, 102x83mm
PCB thickness, 1.6mm
number of layers, 2
soldermask color, Black
silkscreen color, White
oz copper, 1oz
finish, HASL lead free
stencils, bottom
pcs per panel, 6

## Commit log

2018-11-07 post design review
    [QwiicHUD.brd, QwiicHUD.sch]
2018-11-09 post checklist changes
    [QwiicHUD.sch]
2018-11-13 updating bom
    [QwiicHUD.brd, QwiicHUD.sch]
2018-11-15 Created panel v10
    [14138-QwiicHUD-Panel.GBL, 14138-QwiicHUD-Panel.GBO, 14138-QwiicHUD-Panel.GBS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]

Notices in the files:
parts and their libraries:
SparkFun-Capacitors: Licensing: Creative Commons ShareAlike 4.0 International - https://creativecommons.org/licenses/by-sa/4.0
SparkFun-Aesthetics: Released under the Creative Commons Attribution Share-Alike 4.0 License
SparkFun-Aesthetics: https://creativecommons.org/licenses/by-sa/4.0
